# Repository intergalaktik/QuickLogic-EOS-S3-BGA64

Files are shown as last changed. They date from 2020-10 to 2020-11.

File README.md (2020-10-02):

# QuickLogic-EOS-S3-BGA64

## Pinout sorted by BGA pins

Signal Name|Signal Type|I/O Bank|WCLSP Ball|BGA Ball|QFNc|Description|Alternate Function
--|--|--|--|--|--|--|--
IO_2|IO|VCCIOA|--|A1|6||FBIO_2, SPI_SENSOR_SSn2, DEBUG_MON_0, BATT_MON, SENSOR_INT_1 
IO_3|IO|VCCIOA|C7|A2|2||FBIO_3, SENSOR_INT_0 
IO_7|IO|VCCIOA|--|A3|63||FBIO_7, SPI_SENSOR_SSn5, DEBUG_MON_4, SWV, SENSOR_INT_4 
IO_7|IO|VCCIOA|--|A3|63||FBIO_7, SPI_SENSOR_SSn5, DEBUG_MON_4, SWV, SENSOR_INT_4 
IO_10|IO|VCCIOA|B5|A4|59||FBIO_10, SPI_SENSOR_CLK, SWV, SENSOR_INT_4, I2S_DIN, PDM_DIN 
IO_14|IO|VCCIOA|A4|A5|54||FBIO_14, SW_DP_CLK, IrDA_SIROUT, SCL_1, GPIO(3), UART_RXD, SENSOR_INT_5 
LDO_VIN|POWER||B3|A6|50,52|Internal LDO Power Input |
ADC0|ANALOG|ANALOG|B2|A7|48|ADC 0 Input |
AGND|ANA||C3|A8|43|Analog Ground|
IO_0|IO|VCCIOA|A7|B1|4||FBIO_0a, SCL_0 
IO_4|IO|VCCIOA|--|B2|3||FBIO_4, SPI_SENSOR_SSn3, DEBUG_MON_1, SDA_1_DPU, SENSOR_INT_2 
IO_6|IO|VCCIOA|A6|B3|62||FBIO_6, SPI_SENSOR_MOSI, DEBUG_MON_3, FCLK, GPIO(0)b, IrDA_SIRIN, SENSOR_INT_1 
IO_9|IO|VCCIOA|A5|B4|60||FBIO_9, SPI_SENSOR_SSn1, I2S_WD_CLK_O, GPIO(1),PDM_STAT_I, SENSOR_INT_3 
IO_12|IO|VCCIOA|--|B5|56||FBIO_12, SPI_SENSOR_SSn7, DEBUG_MON_6, IrDA_SIROUT, SENSOR_INT_6 
VDD2|POWER||A3|B6|51|LDO 2 Output|
VDD1|POWER||A2|B7|49|LDO 1 Output|
XTAL_IN|ANALOG|ANALOG|A1|B8|44|32 kHz Crystal|32 kHz Clock Input 
IO_1|IO|VCCIOA|B7|C1|5||FBIO_1, SDA_0 
VCCIOA|POWER||C6|C2|1, 58|Bank A VCC In|
IO_5|IO|VCCIOA|--|C3|64||FBIO_5, SPI_SENSOR_SSn4, DEBUG_MON_2, SDA_0_DPU, SENSOR_INT_3
IO_8|IO|VCCIOA|B6|C4|61||FBIO_8, PDM_CLK_O, I2S_CLK_O, IrDA_SIROUT, SENSOR_INT_2 
IO_11|IO|VCCIOA|--|C5|57||FBIO_11, SPI_SENSOR_SSn6, DEBUG_MON_5, GPIO(2), SENSOR_INT_5 
IO_15|IO|VCCIOA|B4|C6|53||FBIO_15, SW_DP_IO, IrDA_SIRIN, SDA_1, UART_TXD, SENSOR_INT_6 
ADC1|ANALOG|ANALOG|--|C7|47|ADC 1 Input |
XTAL_OUT|ANALOG|ANALOG|B1|C8|45|32 kHz Crystal |
IO_43|IO|VCCIOB|D7|D1|7||FBIO_43, AP_INTERRUPT IO_44 IO VCCIOB E7 E1 8 FB
IO_40|IO|VCCIOB|--|D2|13||SPI_MASTER_SSn1, FBIO_40, SCL_2, DEBUG_MON_5, IrDA_SIRIN, SENSOR_INT_3
GND|GND||C4,C5|D3,D4,D5|GND|Ground |
IO_13|IO|VCCIOA|--|D6|55||FBIO_13, SPI_SENSOR_SSn8, DEBUG_MON_7, SWV, SENSOR_INT_7 
IO_17|IO|VCCIOB|D1|D7|42||FBIO_17, SPI_SLAVE_MISO, UART_CTS
AVDD|ANA||C2|D8|46|Analog Power |
IO_44|IO|VCCIOB|E7|E1|8||FBIO_44, SW_DP_IO, SDA_1, UART_TXD, IrDA_SIRIN, SENSOR_INT_4 
IO_38|IO|VCCIOB|E6|E2|16||SPI_MASTER_MOSI, FBIO_38, DEBUG_MON_3, GPIO(6), AP_PDM_CLK_IN, SENSOR_INT_2 
IO_33|IO|VCCIOB|--|E3|21||FBIO_33, SPI_SENSOR_SSn6, DEBUG_MON_7, SCL_1, SENSOR_INT_7
VCCIOB|POWER||D6|E4,E6|12, 24, 35|Bank B VCC In|
STM|INPUT|VCCIOB|D4|E5|29|Connect to ground|
IO_16|IO|VCCIOB|E1|E7|40||FBIO_16, SPI_SLAVE_CLK, UART_RXD 
IO_18|IO|VCCIOB|--|E8|38||FBIO_18, SWV, DEBUG_MON_0, GPIO(4), SENSOR_INT_1 
IO_41|IO|VCCIOB|--|F1|14||FBIO_41, SDA_2, DEBUG_MON_6, IrDA_SIROUT, SENSOR_INT_6
IO_35|IO|VCCIOB|--|F2|18||FBIO_35, SPI_MASTER_SSn3, SPI_SENSOR_SSn7, DEBUG_MON_1, SENSOR_INT_1 
IO_34|IO|VCCIOB|D5|F3|20||SPI_MASTER_CLK, FBIO_34, DEBUG_MON_0, AP_PDM_STAT_O, SENSOR_INT_7 
IO_30|IO|VCCIOB|F4|F4|25||FBIO_30, SPI_SENSOR_SSn1, GPIO(3), I2S_WD_CLK_O, PDM_STAT_I, SENSOR_INT_5 
IO_29|IO|VCCIOB|E3|F5|26||FBIO_29, SPI_SENSOR_MISO, I2S_CLK_O, PDM_CLK_O, IrDA_SIROUT, SENSOR_INT_4 
IO_26|IO|VCCIOB|--|F6|30||FBIO_26, SPI_SENSOR_SSn3, DEBUG_MON_3, GPIO(1), SENSOR_INT_4 
IO_25|IO|VCCIOB|D3|F7|31||FBIO_25, SPI_MASTER_SSn3, SWV, IrDA_SIROUT, UART_RXD, SENSOR_INT_2 
SYS_RSTn|INPUT|VCCIOB|F1|F8|41|System Reset Input|
IO_45|IO|VCCIOB|F7|G1|9||FBIO_45, SW_DP_CLK, SCL_1, UART_RXD, IrDA_SIROUT, GPIO(7), SENSOR_INT_5
IO_37|IO|VCCIOB|--|G2|15||FBIO_37, SPI_SENSOR_SSn8, DEBUG_MON_2, SDA_2_DPU, SENSOR_INT_2 
FSOURCE|VPP||E5|G3|19|Connect to ground |
IO_31|IO|VCCIOB|E4|G4|23||FBIO_31, SPI_SENSOR_CLK, GPIO(4), AP_I2S_CLK_IN, SENSOR_INT_6 
IO_28|IO|VCCIOB|F3|G5|27||FBIO_28, SPI_SENSOR_MOSI, DEBUG_MON_5, GPIO(2), I2S_DIN, PDM_DIN, IrDA_SIRIN, SENSOR_INT_3
IO_24|IO|VCCIOB|D2|G6|32||FBIO_24, AP_I2S_DOUT, IrDA_SIRIN, GPIO(0)b, UART_TXD, SENSOR_INT_1 
IO_22|IO|VCCIOB|--|G7|34||FBIO_22, DEBUG_MON_2, IrDA_SIROUT, GPIO(6), UART_CTS, SENSOR_INT_3
IO_20|IO|VCCIOB|F2|G8|37||FBIO_20, SPI_SLAVE_SSn, UART_TXD IO_21 IO VCCIOB -- H7 39 FB
IO_42|IO|VCCIOB|--|H1|10||FBIO_42, SDA_1_DPU, DEBUG_MON_7, SWV, SENSOR_INT_7
IO_39|IO|VCCIOB|F6|H2|11||FBIO_39, DEBUG_MON_4, AP_PDM_IO, SENSOR_INT_3 
IO_36|IO|VCCIOB|F5|H3|17||SPI_MASTER_MISO, FBIO_36, SWV, SPI_SENSOR_SSn2, GPIO(5), SENSOR_INT_1 
IO_32|IO|VCCIOB|--|H4|22||FBIO_32, SPI_SENSOR_SSn5, DEBUG_MON_6, SDA_1, SENSOR_INT_6
IO_27|IO|VCCIOB|--|H5|28||FBIO_27, SPI_MASTER_SSn2, SPI_SENSOR_SSn4, DEBUG_MON_4, SENSOR_INT_5 
IO_23|IO|VCCIOB|E2|H6|33||FBIO_23, SPI_MASTER_SSn2, SWV, GPIO(7), AP_I2S_WD_CLK_IN, SENSOR_INT_7 
IO_21|IO|VCCIOB|--|H7|39||FBIO_21, DEBUG_MON_1, IrDA_SIRIN, GPIO(5), UART_RTS, SENSOR_INT_2 
IO_19|IO|VCCIOB|C1|H8|36||FBIO_19, SPI_SLAVE_MOSI, UART_RTS Note: IO_19 can serve as bootstrap for debugger mode as an M4-F reset release mechanism. 

Symbol library taken from: QuickFeather Development Board

https://github.com/QuickLogic-Corp/quick-feather-dev-board

Revorked to BGA64 by Intergalaktik

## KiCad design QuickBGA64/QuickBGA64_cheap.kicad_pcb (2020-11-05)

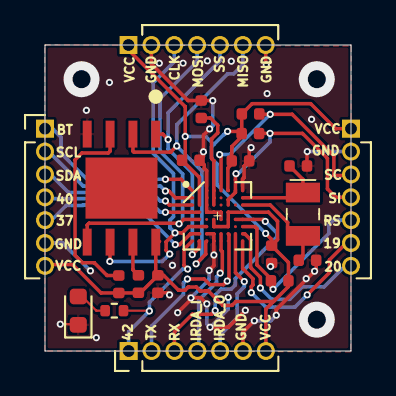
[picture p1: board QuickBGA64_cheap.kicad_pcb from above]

Board: 2 copper layers, 17.0 x 17.0 mm, 21 parts (0 on the bottom side), 27 nets.

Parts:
C1, C2: 12pF; C_0402_1005Metric
C3, C4, C5, C6: 100n; C_0402_1005Metric
D1: LED; LED_0603_1608Metric
IC1: EOS-S3-BGA64; BGA-64_3.5x3.5mm_Layout8x8_P0.4mm_cheap
J1: TOP; PinHeader_1x07_P1.27mm_Vertical
J2: RIGHT; PinHeader_1x07_P1.27mm_Vertical
J3: BOTTOM; PinHeader_1x07_P1.27mm_Vertical
J4: LEFT; PinHeader_1x07_P1.27mm_Vertical
R1, R2, R3, R4, R5, R6: 10K; R_0402_1005Metric
R7: R300; R_0402_1005Metric
U1: GD25Q16CWIGR; GD25Q16CWIG
Y1: ECS-_327-12_5-34B-TR; SMD-2_3.2x1.5mm

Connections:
/37: IC1.G2, J4.5
/40: IC1.D1, IC1.D2, J4.4
/42: IC1.H1, J3.1, R7.2
/BAT_M: IC1.A1, J4.1
/B_19: IC1.H8, J2.6
/B_20: IC1.G8, J2.7
/CLK: IC1.F1, IC1.F2, IC1.F3, J1.3, U1.6
/HS_OSC_9: IC1.A4, IC1.B4, IC1.C4, R4.1
/IrDA_I: IC1.G5, IC1.H5, J3.4
/IrDA_O: IC1.G7, IC1.H7, J3.5
/MISO: IC1.H3, J1.6, U1.2
/MOSI: IC1.E2, J1.4, U1.5
/RST: IC1.F8, J2.5, R1.2
/RX: IC1.E7, IC1.E8, J3.3
/SCL: IC1.B1, J4.2
/SDA: IC1.C1, J4.3
/SS: IC1.H2, J1.5, U1.1
/SWD_CLK: IC1.A5, J2.3, R6.2
/SWD_IO: IC1.A7, IC1.C6, J2.4, R5.2
/TX: IC1.G6, IC1.H6, J3.2
/X0: C2.1, IC1.C8, Y1.2
/X1: C1.1, IC1.B8, Y1.1
GND: C1.2, C2.2, C3.1, C4.1, C5.1, C6.1, D1.1, IC1.A3, IC1.A8, IC1.B3, IC1.C3, IC1.D3, IC1.D4, IC1.D5, IC1.E5, IC1.G3, IC1.G4, IC1.H4, J1.2, J1.7, J2.2, J3.6, J4.6, R4.2, U1.4
unnamed: D1.2, R7.1
unnamed: R2.2, U1.7
unnamed: R3.2, U1.3
VCC: C3.2, C4.2, C5.2, C6.2, IC1.A2, IC1.A6, IC1.B2, IC1.C2, IC1.D6, IC1.D8, IC1.E4, IC1.E6, IC1.F4, IC1.F5, IC1.F6, J1.1, J2.1, J3.7, J4.7, R1.1, R2.1, R3.1, R5.1, R6.1, U1.8

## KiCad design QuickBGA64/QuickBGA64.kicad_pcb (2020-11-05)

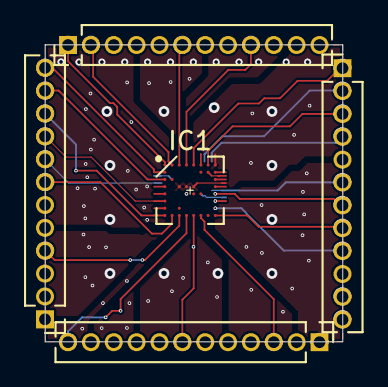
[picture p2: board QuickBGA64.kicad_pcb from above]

Board: 4 copper layers, 16.5 x 16.5 mm, 5 parts (0 on the bottom side), 21 nets.

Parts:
IC1: EOS-S3-BGA64; BGA-64_3.5x3.5mm_Layout8x8_P0.4mm_cheap
J1: TOP; PinHeader_1x12_P1.27mm_Vertical
J2: RIGHT; PinHeader_1x12_P1.27mm_Vertical
J3: BOTOM; PinHeader_1x12_P1.27mm_Vertical
J4: LEFT; PinHeader_1x12_P1.27mm_Vertical

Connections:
/2: IC1.A1, J1.1
/3: IC1.A2, J1.2
/7: IC1.A3, J1.6
/10: IC1.A4, J1.9
/14: IC1.A5, J2.1
/18: IC1.E8, J2.7
/19: IC1.H8, J2.8
/20: IC1.G8, J2.9
/21: IC1.H7, J2.10
/23: IC1.H6, J3.3
/27: IC1.H5, J3.7
/32: IC1.H4, J3.12
/36: IC1.H3, J4.4
/39: IC1.H2, J4.7
/41: IC1.F1, J4.9
/42: IC1.H1, J4.10
/A0: IC1.A7, J2.3
/SCL: IC1.B1, J4.12
/SDA: IC1.C1, J4.11
GND: IC1.A8, IC1.D3, IC1.D4, IC1.D5, J2.12, J3.1
VCC: IC1.A6, IC1.B6, IC1.B7, IC1.C2, IC1.D8, IC1.E4, IC1.E6, J2.11

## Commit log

2020-10-01 Adding initial footprint
2020-10-02 Changing pad sie to 0.25mm
2020-10-02 Adding schematics and pcb
    [QuickBGA64.sch]
2020-10-08 Adding Cheap option
    [QuickBGA64_cheap.kicad_pcb, QuickBGA64_cheap.sch]
2020-11-05 Adding LED, sending to production
    [QuickBGA64.kicad_pcb, QuickBGA64.sch, QuickBGA64_cheap.kicad_pcb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]
